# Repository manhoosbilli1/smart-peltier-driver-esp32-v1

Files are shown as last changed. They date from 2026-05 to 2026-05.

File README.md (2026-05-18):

# daanmem_esp32_board_FO2DABBFD842

Smart Peltier driver, ESP32-S3, v1 (v2 in active development)

## At a Glance

- **Status**: Partial / WIP
- **Board size**: 94.01 x 48.1 mm
- **Layers**: 2
- **Components**: 89
- **Key ICs**:
  - U1: AMS1117-3.3
  - U2: LM66200DRLR
  - U3: TPS62932
  - U4: ESP32-S3-WROOM-1-N16R8
  - U6: SM03B-SRSS-TB(LF)(SN)(P)
  - U7,U8: AHT20_C2757850
  - U9: TPS22811LRPWR_C17294173
  - U10: IRS44273LTRPBF

## Schematic

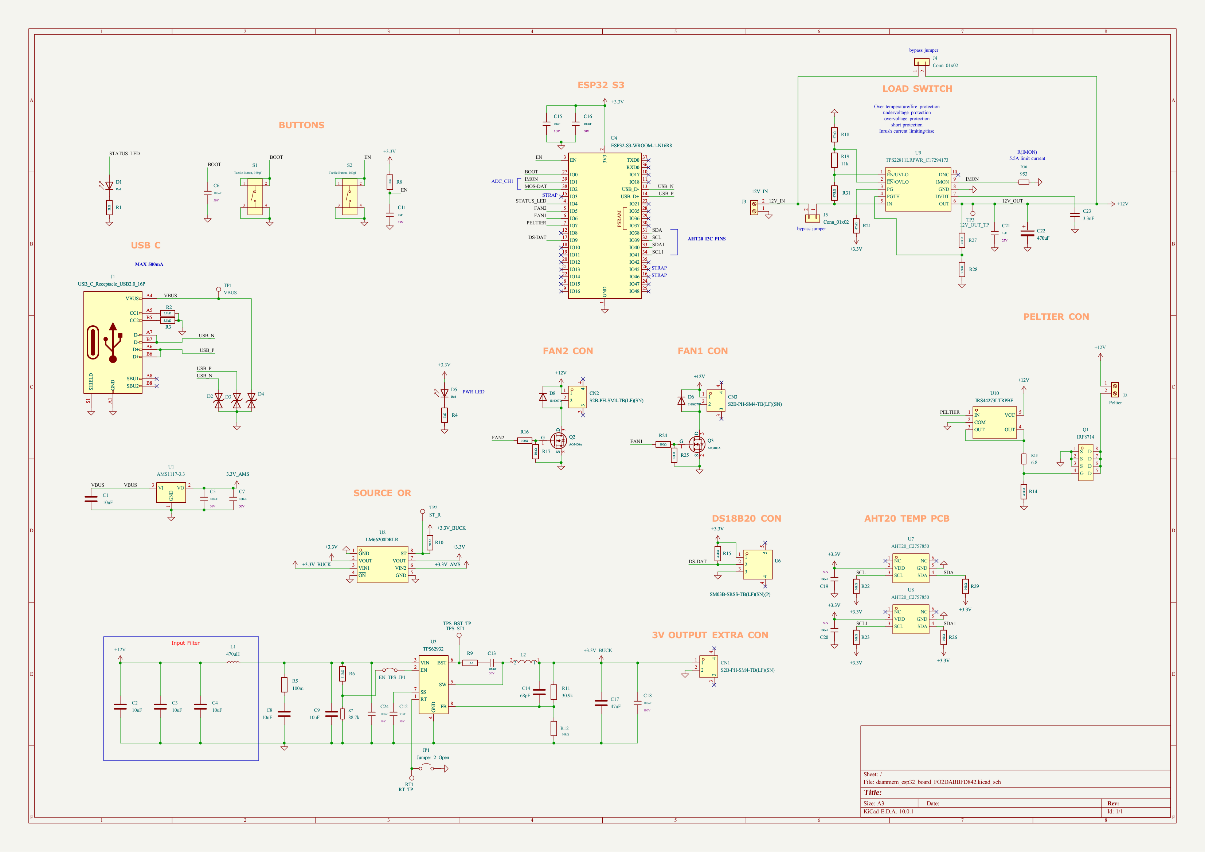
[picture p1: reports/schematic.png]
Schematic


Full PDF: [reports/schematic.pdf](reports/schematic.pdf)

## Component Roles

- **ESP32-S3-WROOM-1** - main MCU; Wi-Fi/BT for remote temperature setpoint + telemetry
- **AMS1117-3.3** - 3.3 V LDO for the MCU core
- **LM66200DRLR** - dual-input ideal-diode / PowerPath controller for clean USB-vs-battery sourcing
- **AO3400A** - 30 V N-channel MOSFETs for switching the Peltier element / fan loads
- **H5VL06B** - small-signal transistors for gate driving / level shifting
- **MCP73831** - single-cell LiPo charger
- **USB-C (16-pin Type-C)** - power + data
- **JST-PH battery connector** (S2B-PH-SM4-TB) for LiPo cell

> v1 reached partial routing (90 footprints placed, 47 tracks, 26 zones). v2 is in active development.

## PCB

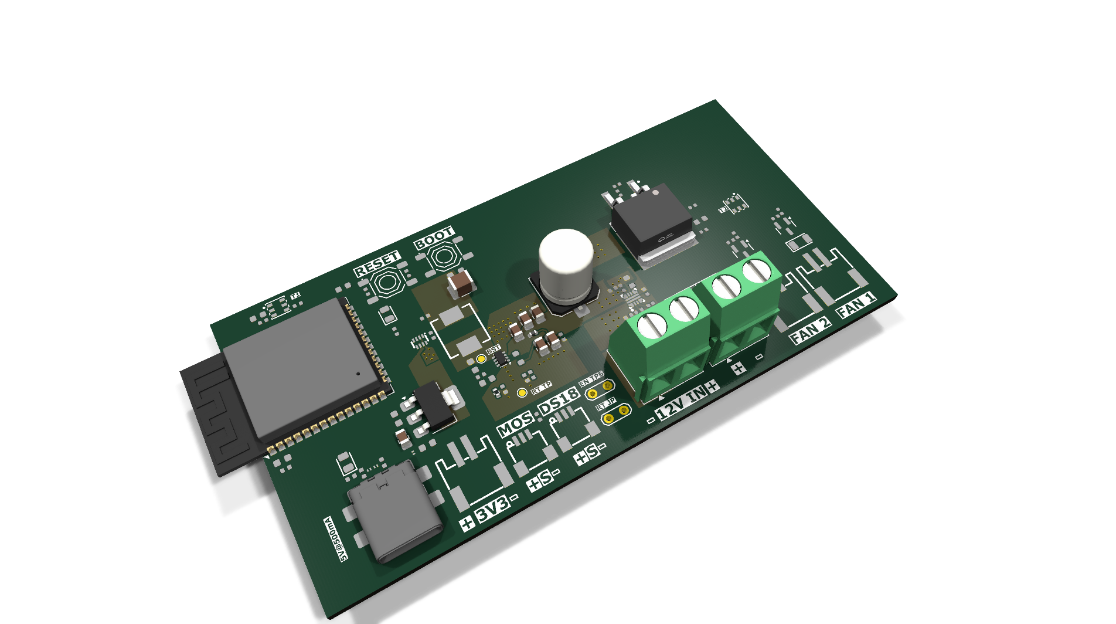
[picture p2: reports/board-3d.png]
3D top


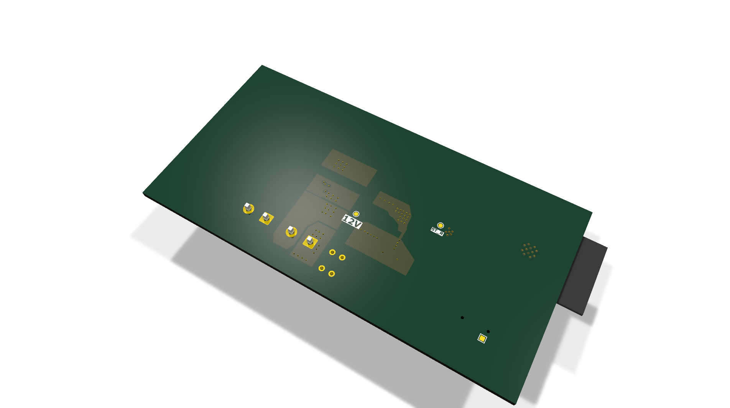
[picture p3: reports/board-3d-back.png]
3D bottom


**Top copper**

PCB top

**Bottom copper**

PCB bottom

## Bill of Materials

| Refs | Value | Footprint | Qty | MPN | LCSC |
|---|---|---|----:|-----|---|
| C1-C4,C8,C9 | 10uF | Capacitor_SMD:C_0805_2012Metric | 6 |  | [C6119887](https://www.lcsc.com/product-detail/_C6119887.html) |
| C5-C7,C13,C16,C19,C20 | 100nF | PCM_JLCPCB:C_0603 | 7 |  | [C14663](https://www.lcsc.com/product-detail/_C14663.html) |
| C11,C21 | 1uF | PCM_JLCPCB:C_0402 | 2 |  | [C52923](https://www.lcsc.com/product-detail/_C52923.html) |
| C12 | 33nF | PCM_JLCPCB:C_0603 | 1 |  | [C21117](https://www.lcsc.com/product-detail/_C21117.html) |
| C14 | 68pF | PCM_JLCPCB:R_0402 | 1 |  | [C76977](https://www.lcsc.com/product-detail/_C76977.html) |
| C15 | 10uF | PCM_JLCPCB:C_0402 | 1 |  | [C15525](https://www.lcsc.com/product-detail/_C15525.html) |
| C17 | 47uF | Capacitor_SMD:C_1210_3225Metric | 1 |  | [C77101](https://www.lcsc.com/product-detail/_C77101.html) |
| C18 | 100nF | PCM_JLCPCB:C_0805 | 1 |  | [C28233](https://www.lcsc.com/product-detail/_C28233.html) |
| C22 | 470uF | Capacitor_SMD:C_Elec_8x10.2 | 1 |  | [C141429](https://www.lcsc.com/product-detail/_C141429.html) |
| C23 | 3.3nF | PCM_JLCPCB:R_0603 | 1 |  | [C77036](https://www.lcsc.com/product-detail/_C77036.html) |
| C24 | 100nF | PCM_JLCPCB:C_0402 | 1 |  | [C1525](https://www.lcsc.com/product-detail/_C1525.html) |
| CN1-CN3 | S2B-PH-SM4-TB(LF)(SN) | :CONN-SMD_P2.00_S2B-PH-SM4-TB-LF-SN | 3 |  |  |
| D1,D5 | Red | PCM_JLCPCB:D_0805 | 2 |  | [C84256](https://www.lcsc.com/product-detail/_C84256.html) |
| D2-D4 | H5VL06B | PCM_JLCPCB:D_DFN0603-2L | 3 |  | [C7420373](https://www.lcsc.com/product-detail/_C7420373.html) |
| D6,D8 | 1N4007W | PCM_JLCPCB:D_SOD-123FL | 2 |  | [C18199088](https://www.lcsc.com/product-detail/_C18199088.html) |
| EN_TPS_JP1 | Jumper_2_Bridged | TestPoint:TestPoint_2Pads_Pitch2.54mm_Drill0.8mm | 1 |  |  |
| J1 | USB_C_Receptacle_USB2.0_16P | Connector_USB:USB_C_Receptacle_GCT_USB4110 | 1 |  |  |
| J2 | Peltier | TerminalBlock_Phoenix:TerminalBlock_Phoenix_MKDS-1,5-2-5.08_1x02_P5.08mm_Horizontal | 1 |  | [C7509570](https://www.lcsc.com/product-detail/_C7509570.html) |
| J3 | 12V_IN | TerminalBlock_Phoenix:TerminalBlock_Phoenix_MKDS-1,5-2-5.08_1x02_P5.08mm_Horizontal | 1 |  | [C7509570](https://www.lcsc.com/product-detail/_C7509570.html) |
| J4,J5 | Conn_01x02 | Connector_JST:JST_XH_B2B-XH-AM_1x02_P2.50mm_Vertical | 2 |  |  |
| JP1 | Jumper_2_Open | TestPoint:TestPoint_2Pads_Pitch2.54mm_Drill0.8mm | 1 |  |  |
| L1 | 470uH | Inductor_SMD:L_0402_1005Metric | 1 |  | [C5788770](https://www.lcsc.com/product-detail/_C5788770.html) |
| L2 | TMPC0624H-6R8MG-D | inductor_6.8u:IND-SMD_L7.0-W6.6 | 1 |  |  |
| Q1 | IRF8714 | :SOIC-8_L4.9-W3.9-P1.27-LS6.0-BL | 1 |  |  |
| Q2,Q3 | AO3400A | PCM_JLCPCB:Q_SOT-23 | 2 |  | [C20917](https://www.lcsc.com/product-detail/_C20917.html) |
| R1 | 2kΩ | PCM_JLCPCB:R_0402 | 1 |  | [C4109](https://www.lcsc.com/product-detail/_C4109.html) |
| R2,R3 | 5.1kΩ | PCM_JLCPCB:R_0402 | 2 |  | [C25905](https://www.lcsc.com/product-detail/_C25905.html) |
| R4 | 1kΩ | PCM_JLCPCB:R_0402 | 1 |  | [C11702](https://www.lcsc.com/product-detail/_C11702.html) |
| R5 | 100m | PCM_JLCPCB:R_0603 | 1 |  | [C713431](https://www.lcsc.com/product-detail/_C713431.html) |
| R6 | 510kΩ | PCM_JLCPCB:R_0402 | 1 |  | [C11616](https://www.lcsc.com/product-detail/_C11616.html) |
| R7 | 88.7k | PCM_JLCPCB:R_0402 | 1 |  | [C477808](https://www.lcsc.com/product-detail/_C477808.html) |
| R8,R12,R17,R22,R23,R25,R26,R29 | 10kΩ | PCM_JLCPCB:R_0402 | 8 |  | [C25744](https://www.lcsc.com/product-detail/_C25744.html) |
| R9 | 0Ω | PCM_JLCPCB:R_0402 | 1 |  | [C17168](https://www.lcsc.com/product-detail/_C17168.html) |
| R10 | 300Ω | PCM_JLCPCB:R_0402 | 1 |  | [C25102](https://www.lcsc.com/product-detail/_C25102.html) |
| R11 | 30.9k | Resistor_SMD:R_0402_1005Metric | 1 |  | [C2085168](https://www.lcsc.com/product-detail/_C2085168.html) |
| R13 | 6.8 | PCM_JLCPCB:R_0402 | 1 |  |  |
| R14,R15 | 4.7kΩ | PCM_JLCPCB:R_0402 | 2 |  | [C25900](https://www.lcsc.com/product-detail/_C25900.html) |
| R16,R24 | 100Ω | PCM_JLCPCB:R_0402 | 2 |  | [C25076](https://www.lcsc.com/product-detail/_C25076.html) |
| R18,R21,R27 | 47kΩ | PCM_JLCPCB:R_0402 | 3 |  | [C25792](https://www.lcsc.com/product-detail/_C25792.html) |
| R19 | 11k | PCM_JLCPCB:R_0402 | 1 |  | [C705643](https://www.lcsc.com/product-detail/_C705643.html) |
| R28 | 5.6kΩ | PCM_JLCPCB:R_0402 | 1 |  | [C25908](https://www.lcsc.com/product-detail/_C25908.html) |
| R30 | 953 | PCM_JLCPCB:R_0402 | 1 |  | [C852958](https://www.lcsc.com/product-detail/_C852958.html) |
| R31 | 470kΩ | PCM_JLCPCB:R_0402 | 1 |  | [C25790](https://www.lcsc.com/product-detail/_C25790.html) |
| RT1 | RT_TP | TestPoint:TestPoint_Pad_D1.0mm | 1 |  |  |
| S1,S2 | Tactile Button, 160gf | PCM_JLCPCB:SW-SMD_4P-L5.1-W5.1-P3.70-LS6.5-TL-2 | 2 |  | [C318884](https://www.lcsc.com/product-detail/_C318884.html) |
| TP1 | VBUS | TestPoint:TestPoint_Pad_1.0x1.0mm | 1 |  |  |
| TP2 | ST_R | TestPoint:TestPoint_Pad_D1.0mm | 1 |  |  |
| TP3 | 12V_OUT_TP | TestPoint:TestPoint_Pad_D1.0mm | 1 |  |  |
| TPS_ST1 | TPS_BST_TP | TestPoint:TestPoint_Pad_D1.0mm | 1 |  |  |
| U1 | AMS1117-3.3 | Package_TO_SOT_SMD:SOT-223-3_TabPin2 | 1 |  | [C6186](https://www.lcsc.com/product-detail/_C6186.html) |
| U2 | LM66200DRLR | LM66200:SOT-583-8_L2.1-W1.2-P0.50-LS1.6-BL | 1 |  |  |
| U3 | TPS62932 | Package_TO_SOT_SMD:SOT-583-8 | 1 |  | [C3032935](https://www.lcsc.com/product-detail/_C3032935.html) |
| U4 | ESP32-S3-WROOM-1-N16R8 | RF_Module:ESP32-S3-WROOM-1 | 1 |  | [C2913202](https://www.lcsc.com/product-detail/_C2913202.html) |
| U6 | SM03B-SRSS-TB(LF)(SN)(P) | :CONN-SMD_SM03B-SRSS-TB-LF-SN-P | 1 |  |  |
| U7,U8 | AHT20_C2757850 | aht20:SENSOR-SMD_L3.0-W3.0-P1.00-BR | 2 |  |  |
| U9 | TPS22811LRPWR_C17294173 | tps22811:VQFN-10_L2.0-W2.0-P0.45-TL | 1 |  |  |
| U10 | IRS44273LTRPBF | :SOT-23-5_L3.0-W1.7-P0.95-LS2.8-BR | 1 |  |  |

_18 of 57 line items don't have an LCSC code in the schematic - search [LCSC](https://www.lcsc.com/) or [JLC parts search](https://jlcsearch.tscircuit.com/) by MPN or footprint when sourcing._

## Files

- `daanmem_esp32_board_FO2DABBFD842.kicad_pro` - KiCad project
- `daanmem_esp32_board_FO2DABBFD842.kicad_sch` - schematic source
- `daanmem_esp32_board_FO2DABBFD842.kicad_pcb` - PCB layout source
- `reports/schematic.pdf` - full schematic (printable)
- `reports/bom.csv` - bill of materials
- `reports/pcb-top.svg`, `reports/pcb-bottom.svg` - copper artwork
- `reports/board-stats.json` - KiCad-generated board statistics

---

_Renders and metadata auto-generated by `Backup-KiCadProject.ps1` using KiCad 10.0._

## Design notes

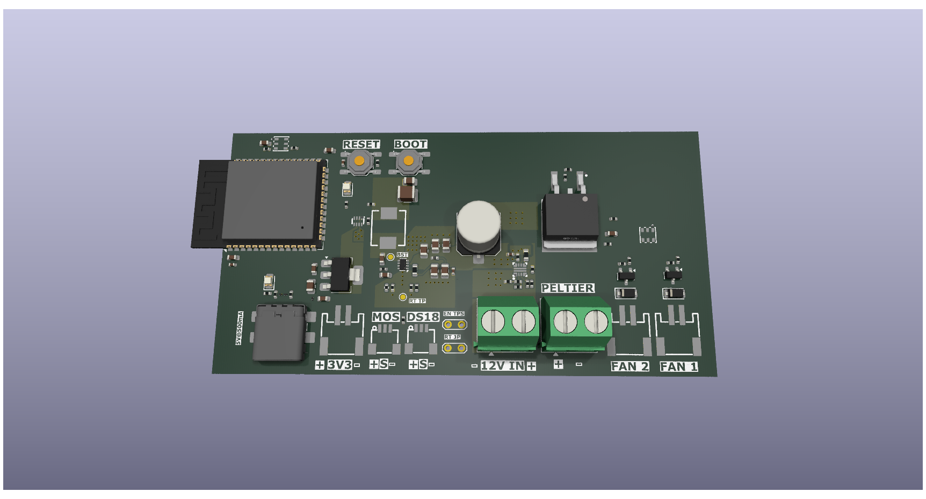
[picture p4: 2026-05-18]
PICTURES/PLACEMENT DRAFT 1.png

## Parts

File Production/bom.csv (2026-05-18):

Designator | Footprint | Quantity | Value | LCSC Part #
C1, C2, C3, C4, C8, C9 | 0805 | 6 | 10uF | C6119887
C11, C21 | C_0402 | 2 | 1uF | C52923
C12 | C_0603 | 1 | 33nF | C21117
C13, C16, C19, C20, C5, C6, C7 | C_0603 | 7 | 100nF | C14663
C14 | R_0402 | 1 | 68pF | C76977
C15 | C_0402 | 1 | 10uF | C15525
C17 | 1210 | 1 | 47uF | C77101
C18 | C_0805 | 1 | 100nF | C28233
C22 | C_Elec_8x10.2 | 1 | 470uF | C141429
C23 | R_0603 | 1 | 3.3nF | C77036
C24 | C_0402 | 1 | 100nF | C1525
CN1, CN2, CN3 | CONN-SMD_P2.00_S2B-PH-SM4-TB-LF-SN | 3 | S2B-PH-SM4-TB(LF)(SN) | C295747
D1, D5 | D_0805 | 2 | Red | C84256
D2, D3, D4 | D_DFN0603-2L | 3 | H5VL06B | C7420373
D6, D8 | D_SOD-123FL | 2 | 1N4007W | C18199088
EN_TPS_JP1 | TestPoint_2Pads_Pitch2.54mm_Drill0.8mm | 1 | Jumper_2_Bridged
J1 | USB_C_Receptacle_GCT_USB4110 | 1 | USB_C_Receptacle_USB2.0_16P
J2 | TerminalBlock_Phoenix_MKDS-1,5-2-5.08_1x02_P5.08mm_Horizontal | 1 | Peltier | C7509570
J3 | TerminalBlock_Phoenix_MKDS-1,5-2-5.08_1x02_P5.08mm_Horizontal | 1 | 12V_IN | C7509570
JP1 | TestPoint_2Pads_Pitch2.54mm_Drill0.8mm | 1 | Jumper_2_Open
L1 | 0402 | 1 | 470uH | C5788770
L2 | IND-SMD_L7.0-W6.6 | 1 | TMPC0624H-6R8MG-D | C357230
Q2, Q3 | Q_SOT-23 | 2 | AO3400A | C20917
Q4 | TO-263-2_L10.0-W9.1-P5.08-LS15.2-TL | 1 | IRF540NSTRLPBF | C23982
R1, R4 | R_0402 | 2 | 2kΩ | C4109
R10 | R_0402 | 1 | 300Ω | C25102
R11 | 0402 | 1 | 30.9k | C2085168
R12, R17, R22, R23, R25, R26, R29, R8 | R_0402 | 8 | 10kΩ | C25744
R13, R16, R24 | R_0402 | 3 | 100Ω | C25076
R14 | R_0402 | 1 | 100kΩ | C25741
R15 | R_0402 | 1 | 4.7kΩ | C25900
R18, R20, R21, R27 | R_0402 | 4 | 47kΩ | C25792
R19 | R_0402 | 1 | 11k | C705643
R2, R3 | R_0402 | 2 | 5.1kΩ | C25905
R28 | R_0402 | 1 | 5.6kΩ | C25908
R30 | R_0402 | 1 | 953 | C852958
R5 | R_0603 | 1 | 100m | C713431
R6 | R_0402 | 1 | 510kΩ | C11616
R7 | R_0402 | 1 | 88.7k | C477808
R9 | R_0402 | 1 | 0Ω | C17168
RT1 | TestPoint_Pad_D1.0mm | 1 | RT_TP
S1, S2 | SW-SMD_4P-L5.1-W5.1-P3.70-LS6.5-TL-2 | 2 | Tactile Button, 160gf | C318884
TP1 | TestPoint_Pad_1.0x1.0mm | 1 | VBUS
TP2 | TestPoint_Pad_D1.0mm | 1 | ST_R
TP3 | TestPoint_Pad_D1.0mm | 1 | 12V_OUT_TP
TPS_ST1 | TestPoint_Pad_D1.0mm | 1 | TPS_BST_TP
U1 | SOT-223-3_TabPin2 | 1 | AMS1117-3.3 | C6186
U2 | SOT-583-8_L2.1-W1.2-P0.50-LS1.6-BL | 1 | LM66200DRLR | C3235556
U3 | SOT-583-8 | 1 | TPS62932 | C3032935
U4 | ESP32-S3-WROOM-1 | 1 | ESP32-S3-WROOM-1-N16R8 | C2913202
U5, U6 | CONN-SMD_SM03B-SRSS-TB-LF-SN-P | 2 | SM03B-SRSS-TB(LF)(SN)(P) | C160403
U7, U8 | SENSOR-SMD_L3.0-W3.0-P1.00-BR | 2 | AHT20_C2757850 | C2757850
U9 | VQFN-10_L2.0-W2.0-P0.45-TL | 1 | TPS22811LRPWR_C17294173 | C17294173

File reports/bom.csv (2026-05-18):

Refs | Value | Footprint | Qty | Description | Mfr | MPN | LCSC
C1-C4,C8,C9 | 10uF | Capacitor_SMD:C_0805_2012Metric | 6 | 10uF ±10% 25V Ceramic Capacitor X5R 0805 |  |  | C6119887
C5-C7,C13,C16,C19,C20 | 100nF | PCM_JLCPCB:C_0603 | 7 | 50V 100nF X7R ±10% 0603 Multilayer Ceramic Capacitors MLCC - SMD/SMT ROHS | YAGEO |  | C14663
C11,C21 | 1uF | PCM_JLCPCB:C_0402 | 2 | 25V 1uF X5R ±10% 0402 Multilayer Ceramic Capacitors MLCC - SMD/SMT ROHS | Samsung Electro-Mechanics |  | C52923
C12 | 33nF | PCM_JLCPCB:C_0603 | 1 | 50V 33nF X7R ±10% 0603 Multilayer Ceramic Capacitors MLCC - SMD/SMT ROHS | Samsung Electro-Mechanics |  | C21117
C14 | 68pF | PCM_JLCPCB:R_0402 | 1 | 68pF ±5% 50V Ceramic Capacitor C0G 0402 |  |  | C76977
C15 | 10uF | PCM_JLCPCB:C_0402 | 1 | 6.3V 10uF X5R ±20% 0402 Multilayer Ceramic Capacitors MLCC - SMD/SMT ROHS | Samsung Electro-Mechanics |  | C15525
C17 | 47uF | Capacitor_SMD:C_1210_3225Metric | 1 | 47uF ±10% 16V Ceramic Capacitor X5R 1210 |  |  | C77101
C18 | 100nF | PCM_JLCPCB:C_0805 | 1 | 100V 100nF X7R ±10% 0805 Multilayer Ceramic Capacitors MLCC - SMD/SMT ROHS | Samsung Electro-Mechanics |  | C28233
C22 | 470uF | Capacitor_SMD:C_Elec_8x10.2 | 1 | Polarized capacitor |  |  | C141429
C23 | 3.3nF | PCM_JLCPCB:R_0603 | 1 | Unpolarized capacitor, small symbol |  |  | C77036
C24 | 100nF | PCM_JLCPCB:C_0402 | 1 | 16V 100nF X7R ±10% 0402 Multilayer Ceramic Capacitors MLCC - SMD/SMT ROHS | Samsung Electro-Mechanics |  | C1525
CN1-CN3 | S2B-PH-SM4-TB(LF)(SN) | :CONN-SMD_P2.00_S2B-PH-SM4-TB-LF-SN | 3
D1,D5 | Red | PCM_JLCPCB:D_0805 | 2 | 25mA Colorless transparent lens 67mcd~195mcd -30°C~+85°C 615nm~630nm Individual diode Red 130° 65mW 1.6V~2.6V 0805 LED Indication - Discrete ROHS | Foshan NationStar Optoelectronics |  | C84256
D2-D4 | H5VL06B | PCM_JLCPCB:D_DFN0603-2L | 3 | 8A 10V 80W 5.6V Bidirectional 5V DFN0603-2L ESD and Surge Protection (TVS/ESD) ROHS | hongjiacheng |  | C7420373
D6,D8 | 1N4007W | PCM_JLCPCB:D_SOD-123FL | 2 | Independent Type 1A 1kV 1V@1.0A SOD-123FL Diodes - General Purpose ROHS | hongjiacheng |  | C18199088
EN_TPS_JP1 | Jumper_2_Bridged | TestPoint:TestPoint_2Pads_Pitch2.54mm_Drill0.8mm | 1 | Jumper, 2-pole, closed/bridged
J1 | USB_C_Receptacle_USB2.0_16P | Connector_USB:USB_C_Receptacle_GCT_USB4110 | 1 | USB 2.0-only 16P Type-C Receptacle connector
J2 | Peltier | TerminalBlock_Phoenix:TerminalBlock_Phoenix_MKDS-1,5-2-5.08_1x02_P5.08mm_Horizontal | 1 | Generic screw terminal, single row, 01x02, script generated (kicad-library-utils/schlib/autogen/connector/) |  |  | C7509570
J3 | 12V_IN | TerminalBlock_Phoenix:TerminalBlock_Phoenix_MKDS-1,5-2-5.08_1x02_P5.08mm_Horizontal | 1 | Generic screw terminal, single row, 01x02, script generated (kicad-library-utils/schlib/autogen/connector/) |  |  | C7509570
J4,J5 | Conn_01x02 | Connector_JST:JST_XH_B2B-XH-AM_1x02_P2.50mm_Vertical | 2 | Generic connector, single row, 01x02, script generated (kicad-library-utils/schlib/autogen/connector/)
JP1 | Jumper_2_Open | TestPoint:TestPoint_2Pads_Pitch2.54mm_Drill0.8mm | 1 | Jumper, 2-pole, open
L1 | 470uH | Inductor_SMD:L_0402_1005Metric | 1 | 1.2A 140mΩ 1.2A ±20% 470nH Multilayer inductor 0402 Fixed Inductors RoHS |  |  | C5788770
L2 | TMPC0624H-6R8MG-D | inductor_6.8u:IND-SMD_L7.0-W6.6 | 1
Q1 | IRF8714 | :SOIC-8_L4.9-W3.9-P1.27-LS6.0-BL | 1
Q2,Q3 | AO3400A | PCM_JLCPCB:Q_SOT-23 | 2 | 30V 5.7A 26.5mΩ@10V,5.7A 1.4W 1.5V@250uA 1 N-Channel SOT-23-3L MOSFETs ROHS | Alpha & Omega Semicon |  | C20917
R1 | 2kΩ | PCM_JLCPCB:R_0402 | 1 | 62.5mW Thick Film Resistors 50V ±100ppm/°C ±1% 2kΩ 0402 Chip Resistor - Surface Mount ROHS | UNI-ROYAL(Uniroyal Elec) |  | C4109
R2,R3 | 5.1kΩ | PCM_JLCPCB:R_0402 | 2 | 62.5mW Thick Film Resistors 50V ±100ppm/°C ±1% 5.1kΩ 0402 Chip Resistor - Surface Mount ROHS | UNI-ROYAL(Uniroyal Elec) |  | C25905
R4 | 1kΩ | PCM_JLCPCB:R_0402 | 1 | 62.5mW Thick Film Resistors 50V ±100ppm/°C ±1% 1kΩ 0402 Chip Resistor - Surface Mount ROHS | UNI-ROYAL(Uniroyal Elec) |  | C11702
R5 | 100m | PCM_JLCPCB:R_0603 | 1 | 0ppm/℃~+300ppm/℃ 100mW 100mΩ Current Sense Resistor SMD ±1% 0603 Current Sense Resistors / Shunt Resistors ROHS |  |  | C713431
R6 | 510kΩ | PCM_JLCPCB:R_0402 | 1 | 62.5mW Thick Film Resistors 50V ±100ppm/°C ±1% 510kΩ 0402 Chip Resistor - Surface Mount ROHS | UNI-ROYAL(Uniroyal Elec) |  | C11616
R7 | 88.7k | PCM_JLCPCB:R_0402 | 1 | Resistor, small symbol |  |  | C477808
R8,R12,R17,R22,R23,R25,R26,R29 | 10kΩ | PCM_JLCPCB:R_0402 | 8 | 62.5mW Thick Film Resistors 50V ±100ppm/°C ±1% 10kΩ 0402 Chip Resistor - Surface Mount ROHS | UNI-ROYAL(Uniroyal Elec) |  | C25744
R9 | 0Ω | PCM_JLCPCB:R_0402 | 1 | 62.5mW Thick Film Resistors 50V ±800ppm/°C ±1% 0Ω 0402 Chip Resistor - Surface Mount ROHS | UNI-ROYAL(Uniroyal Elec) |  | C17168
R10 | 300Ω | PCM_JLCPCB:R_0402 | 1 | 62.5mW Thick Film Resistors 50V ±100ppm/°C ±1% 300Ω 0402 Chip Resistor - Surface Mount ROHS | UNI-ROYAL(Uniroyal Elec) |  | C25102
R11 | 30.9k | Resistor_SMD:R_0402_1005Metric | 1 | 30.9kΩ 62.5mW 50V Thick Film Resistor ±1% ±100ppm/℃ 0402 Chip Resistor - Surface Mount RoHS |  |  | C2085168
R13 | 6.8 | PCM_JLCPCB:R_0402 | 1 | Resistor, small symbol
R14,R15 | 4.7kΩ | PCM_JLCPCB:R_0402 | 2 | 62.5mW Thick Film Resistors 50V ±100ppm/°C ±1% 4.7kΩ 0402 Chip Resistor - Surface Mount ROHS | UNI-ROYAL(Uniroyal Elec) |  | C25900
R16,R24 | 100Ω | PCM_JLCPCB:R_0402 | 2 | 62.5mW Thick Film Resistors 50V ±1% ±200ppm/°C 100Ω 0402 Chip Resistor - Surface Mount ROHS | UNI-ROYAL(Uniroyal Elec) |  | C25076
R18,R21,R27 | 47kΩ | PCM_JLCPCB:R_0402 | 3 | 62.5mW Thick Film Resistors 50V ±100ppm/°C ±1% 47kΩ 0402 Chip Resistor - Surface Mount ROHS | UNI-ROYAL(Uniroyal Elec) |  | C25792
R19 | 11k | PCM_JLCPCB:R_0402 | 1 | Resistor |  |  | C705643
R28 | 5.6kΩ | PCM_JLCPCB:R_0402 | 1 | 62.5mW Thick Film Resistors 50V ±100ppm/°C ±1% 5.6kΩ 0402 Chip Resistor - Surface Mount ROHS | UNI-ROYAL(Uniroyal Elec) |  | C25908
R30 | 953 | PCM_JLCPCB:R_0402 | 1 | Resistor, small symbol |  |  | C852958
R31 | 470kΩ | PCM_JLCPCB:R_0402 | 1 | 62.5mW Thick Film Resistors 50V ±100ppm/°C ±1% 470kΩ 0402 Chip Resistor - Surface Mount ROHS | UNI-ROYAL(Uniroyal Elec) |  | C25790
RT1 | RT_TP | TestPoint:TestPoint_Pad_D1.0mm | 1 | test point
S1,S2 | Tactile Button, 160gf | PCM_JLCPCB:SW-SMD_4P-L5.1-W5.1-P3.70-LS6.5-TL-2 | 2 | None Without 50mA 5.1mm 100000 Times 160gf 12V 5.1mm 1.5mm Round Button Standing paste SPST SMD Tactile Switches ROHS | XKB Connectivity |  | C318884
TP1 | VBUS | TestPoint:TestPoint_Pad_1.0x1.0mm | 1 | test point
TP2 | ST_R | TestPoint:TestPoint_Pad_D1.0mm | 1 | test point
TP3 | 12V_OUT_TP | TestPoint:TestPoint_Pad_D1.0mm | 1 | test point
TPS_ST1 | TPS_BST_TP | TestPoint:TestPoint_Pad_D1.0mm | 1 | test point
U1 | AMS1117-3.3 | Package_TO_SOT_SMD:SOT-223-3_TabPin2 | 1 | 1A Low Dropout regulator, positive, 3.3V fixed output, SOT-223 |  |  | C6186
U2 | LM66200DRLR | LM66200:SOT-583-8_L2.1-W1.2-P0.50-LS1.6-BL | 1
U3 | TPS62932 | Package_TO_SOT_SMD:SOT-583-8 | 1 | 3.8-30V, 2A Synchronous Buck Converters with pulse frequency modulation (PFM), SOT583-8 |  |  | C3032935
U4 | ESP32-S3-WROOM-1-N16R8 | RF_Module:ESP32-S3-WROOM-1 | 1 | RF Module, ESP32-S3 SoC, Wi-Fi 802.11b/g/n, Bluetooth, BLE, 32-bit, 3.3V, onboard antenna, SMD |  |  | C2913202
U6 | SM03B-SRSS-TB(LF)(SN)(P) | :CONN-SMD_SM03B-SRSS-TB-LF-SN-P | 1
U7,U8 | AHT20_C2757850 | aht20:SENSOR-SMD_L3.0-W3.0-P1.00-BR | 2
U9 | TPS22811LRPWR_C17294173 | tps22811:VQFN-10_L2.0-W2.0-P0.45-TL | 1
U10 | IRS44273LTRPBF | :SOT-23-5_L3.0-W1.7-P0.95-LS2.8-BR | 1

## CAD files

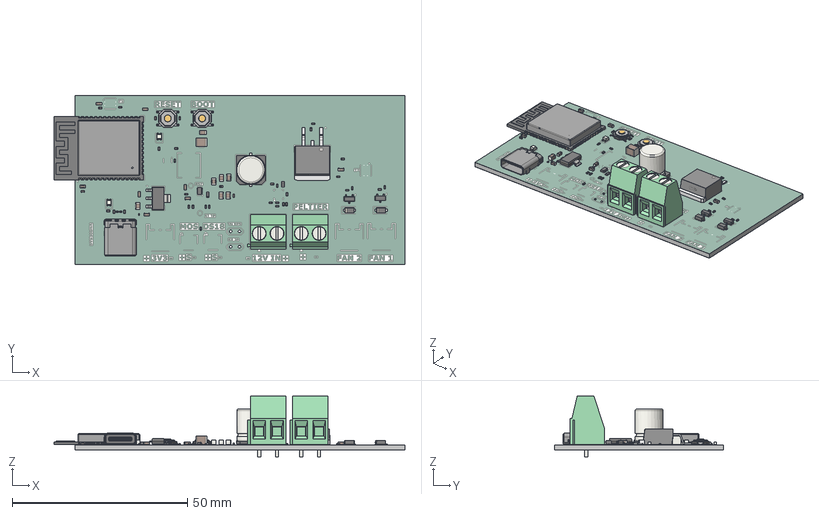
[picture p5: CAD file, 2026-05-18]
daanmem_esp32_board_FO2DABBFD842.step
100.0 x 48.1 x 17.3 mm
R_0402 x 29
C_0603 x 8
C_0805_2012Metric x 6
DFN0603-2_L0.6-W0.3-P0.40-RD x 3
TO-263-2_L10.2-W8.7-H4.5_LS15.2-P2.54
D_SOD-123FL x 2
C_0402 x 4
C_Elec_8x10.2
D_0805 x 2
SOT-583-8
USB_C_Receptacle_Amphenol_12401610E4-2A
R_0603 x 2
C_0805
Q_SOT-23 x 2
R_0402_1005Metric
TerminalBlock_Phoenix_MKDS-1,5-2-5.08_1x02_P5.08mm_Horizontal x 2
SW-SMD_4P-L5.1-W5.1-P3.70-LS6.5-TL-2 x 2
C_1210_3225Metric
L_0402_1005Metric
ESP32-S3-WROOM-1
SOT-223
daanmem_esp32_board_FO2DABBFD842_silkscreen x 2
daanmem_esp32_board_FO2DABBFD842_soldermask x 2
daanmem_esp32_board_FO2DABBFD842_PCB

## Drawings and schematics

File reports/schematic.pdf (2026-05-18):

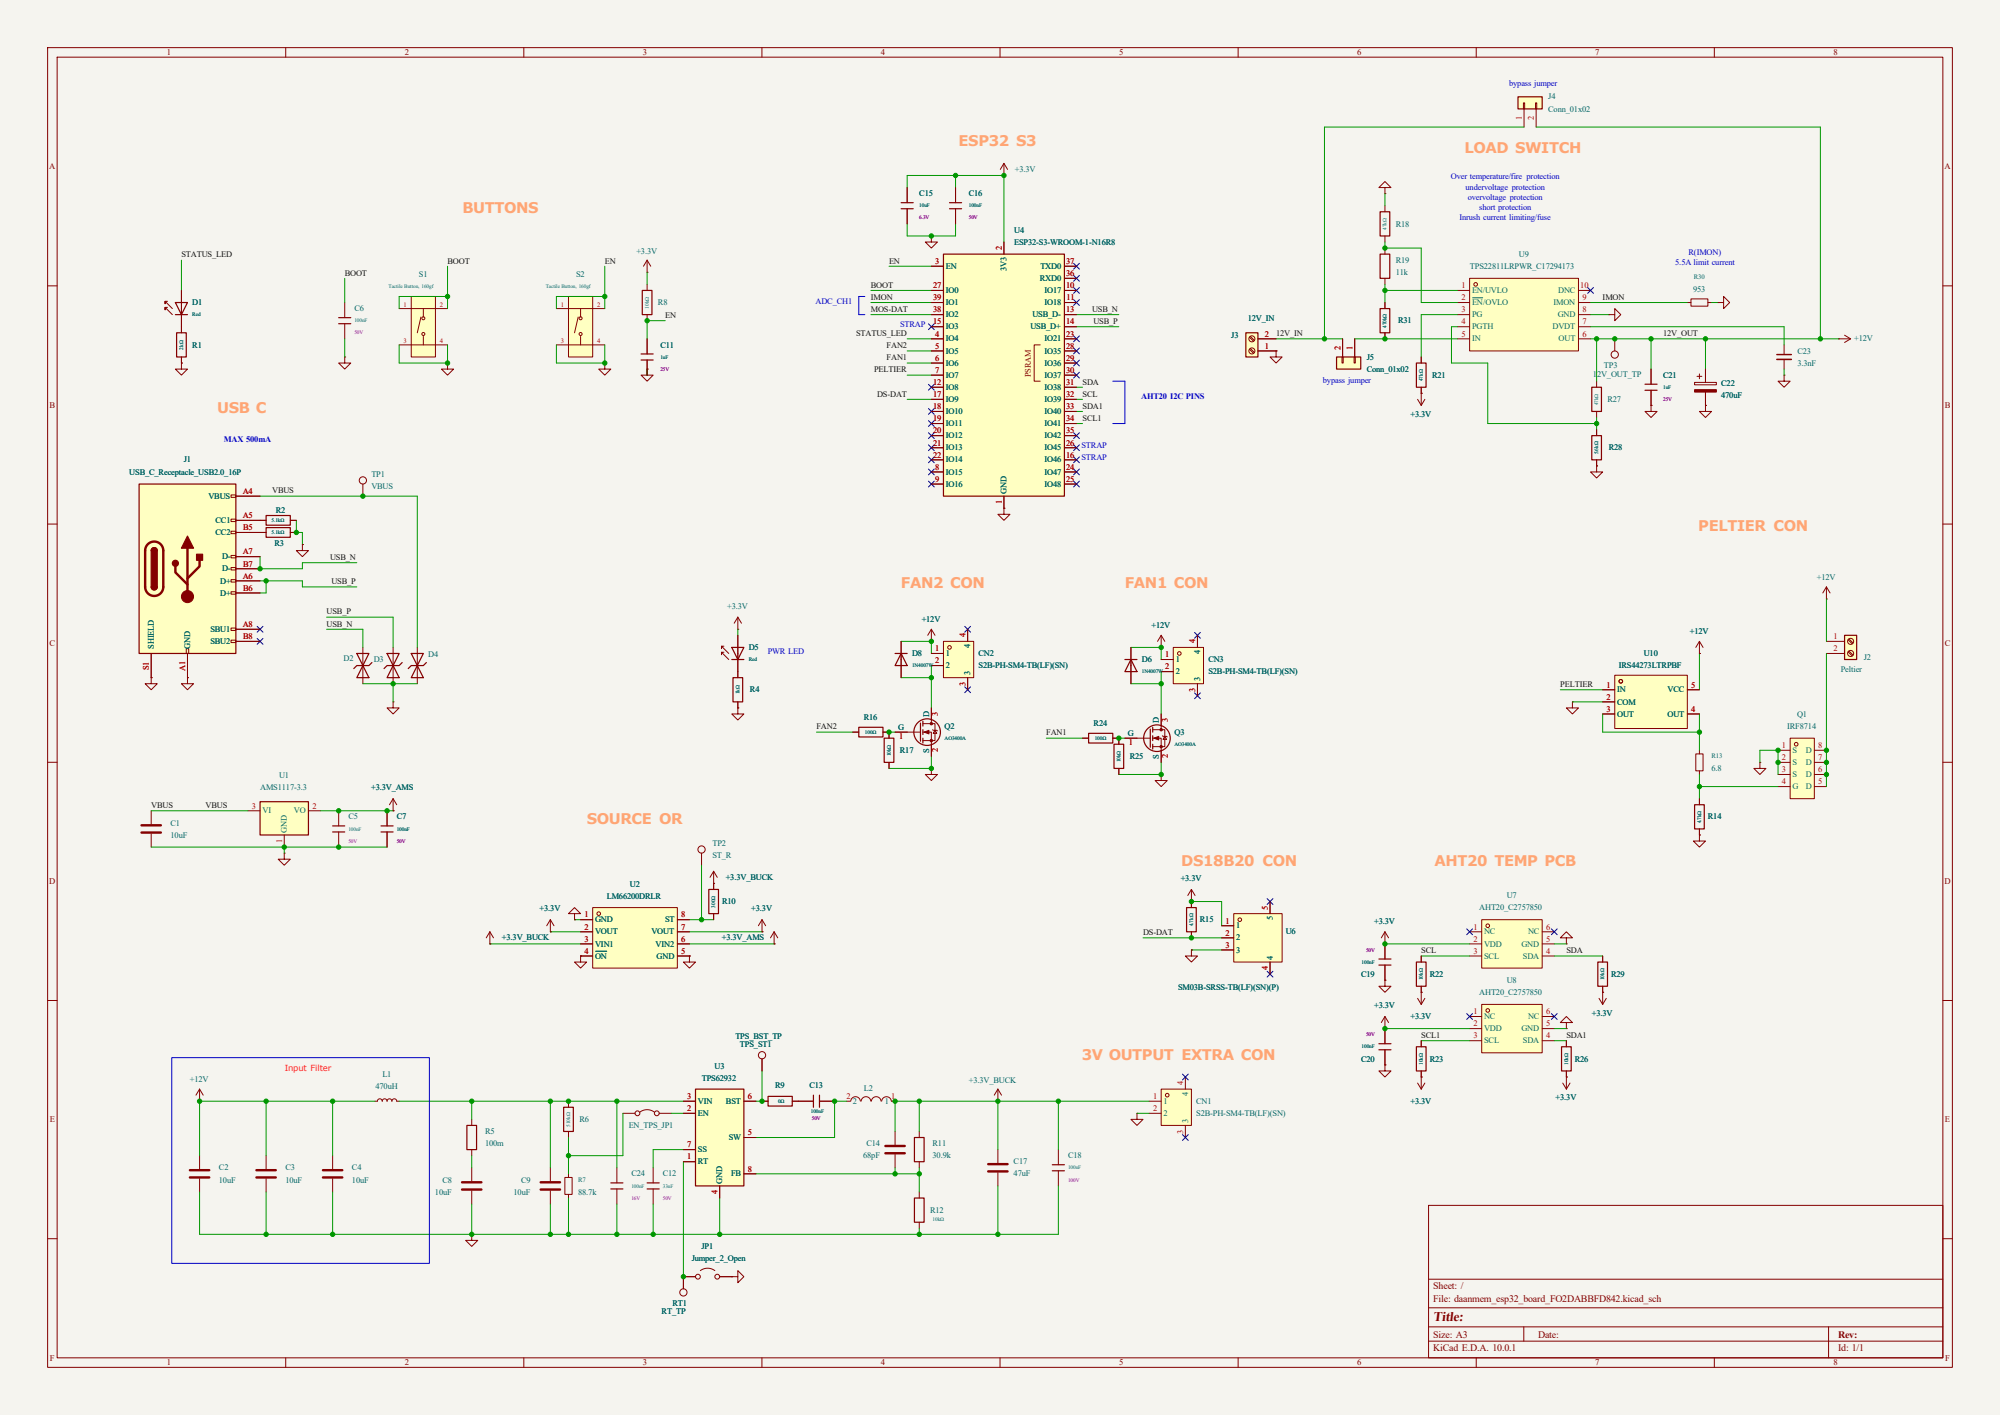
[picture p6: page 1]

bypass jumper Over temperature/fire protection

Inrush current limiting/fuse MAX 500mA

R(IMON) 5.5A limit current 3V OUTPUT EXTRA CON

EN/UVLO 1 EN/OVLO 2 PG 3 PGTH 4

4 SW 5 BST 6 SS 7 FB 8 U3 TPS62932 +3.3V_BUCK +3.3V

4 SW 5 BST 6 SS 7 FB 8 +3.3V_BUCK

5 U6 SM03B-SRSS-TB(LF)(SN)(P)

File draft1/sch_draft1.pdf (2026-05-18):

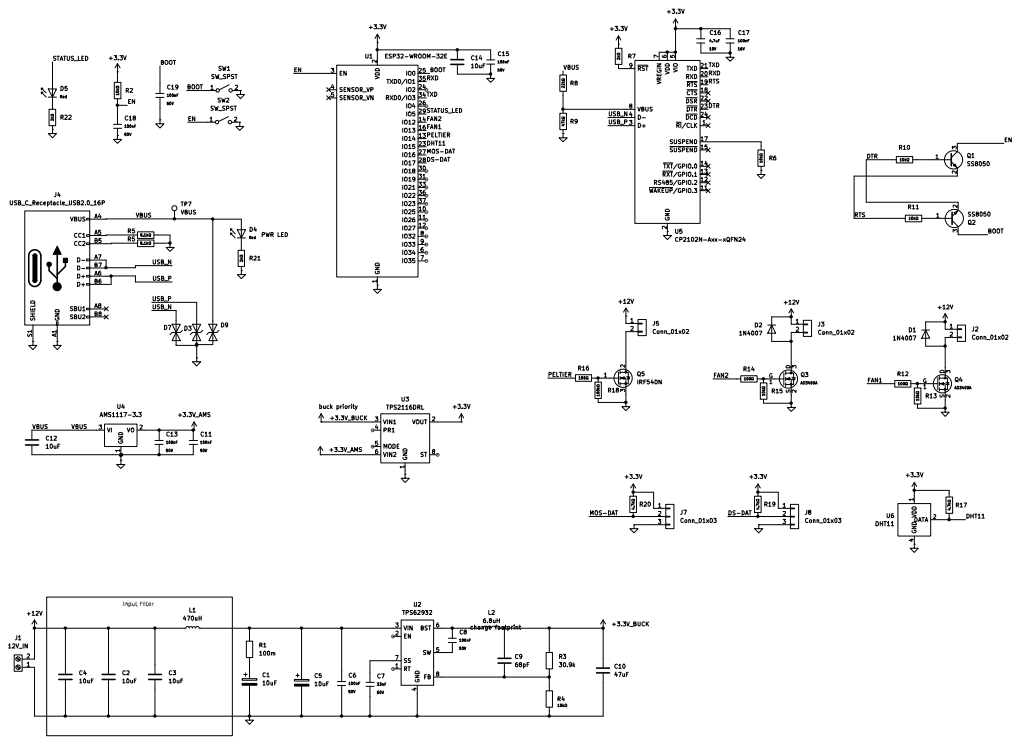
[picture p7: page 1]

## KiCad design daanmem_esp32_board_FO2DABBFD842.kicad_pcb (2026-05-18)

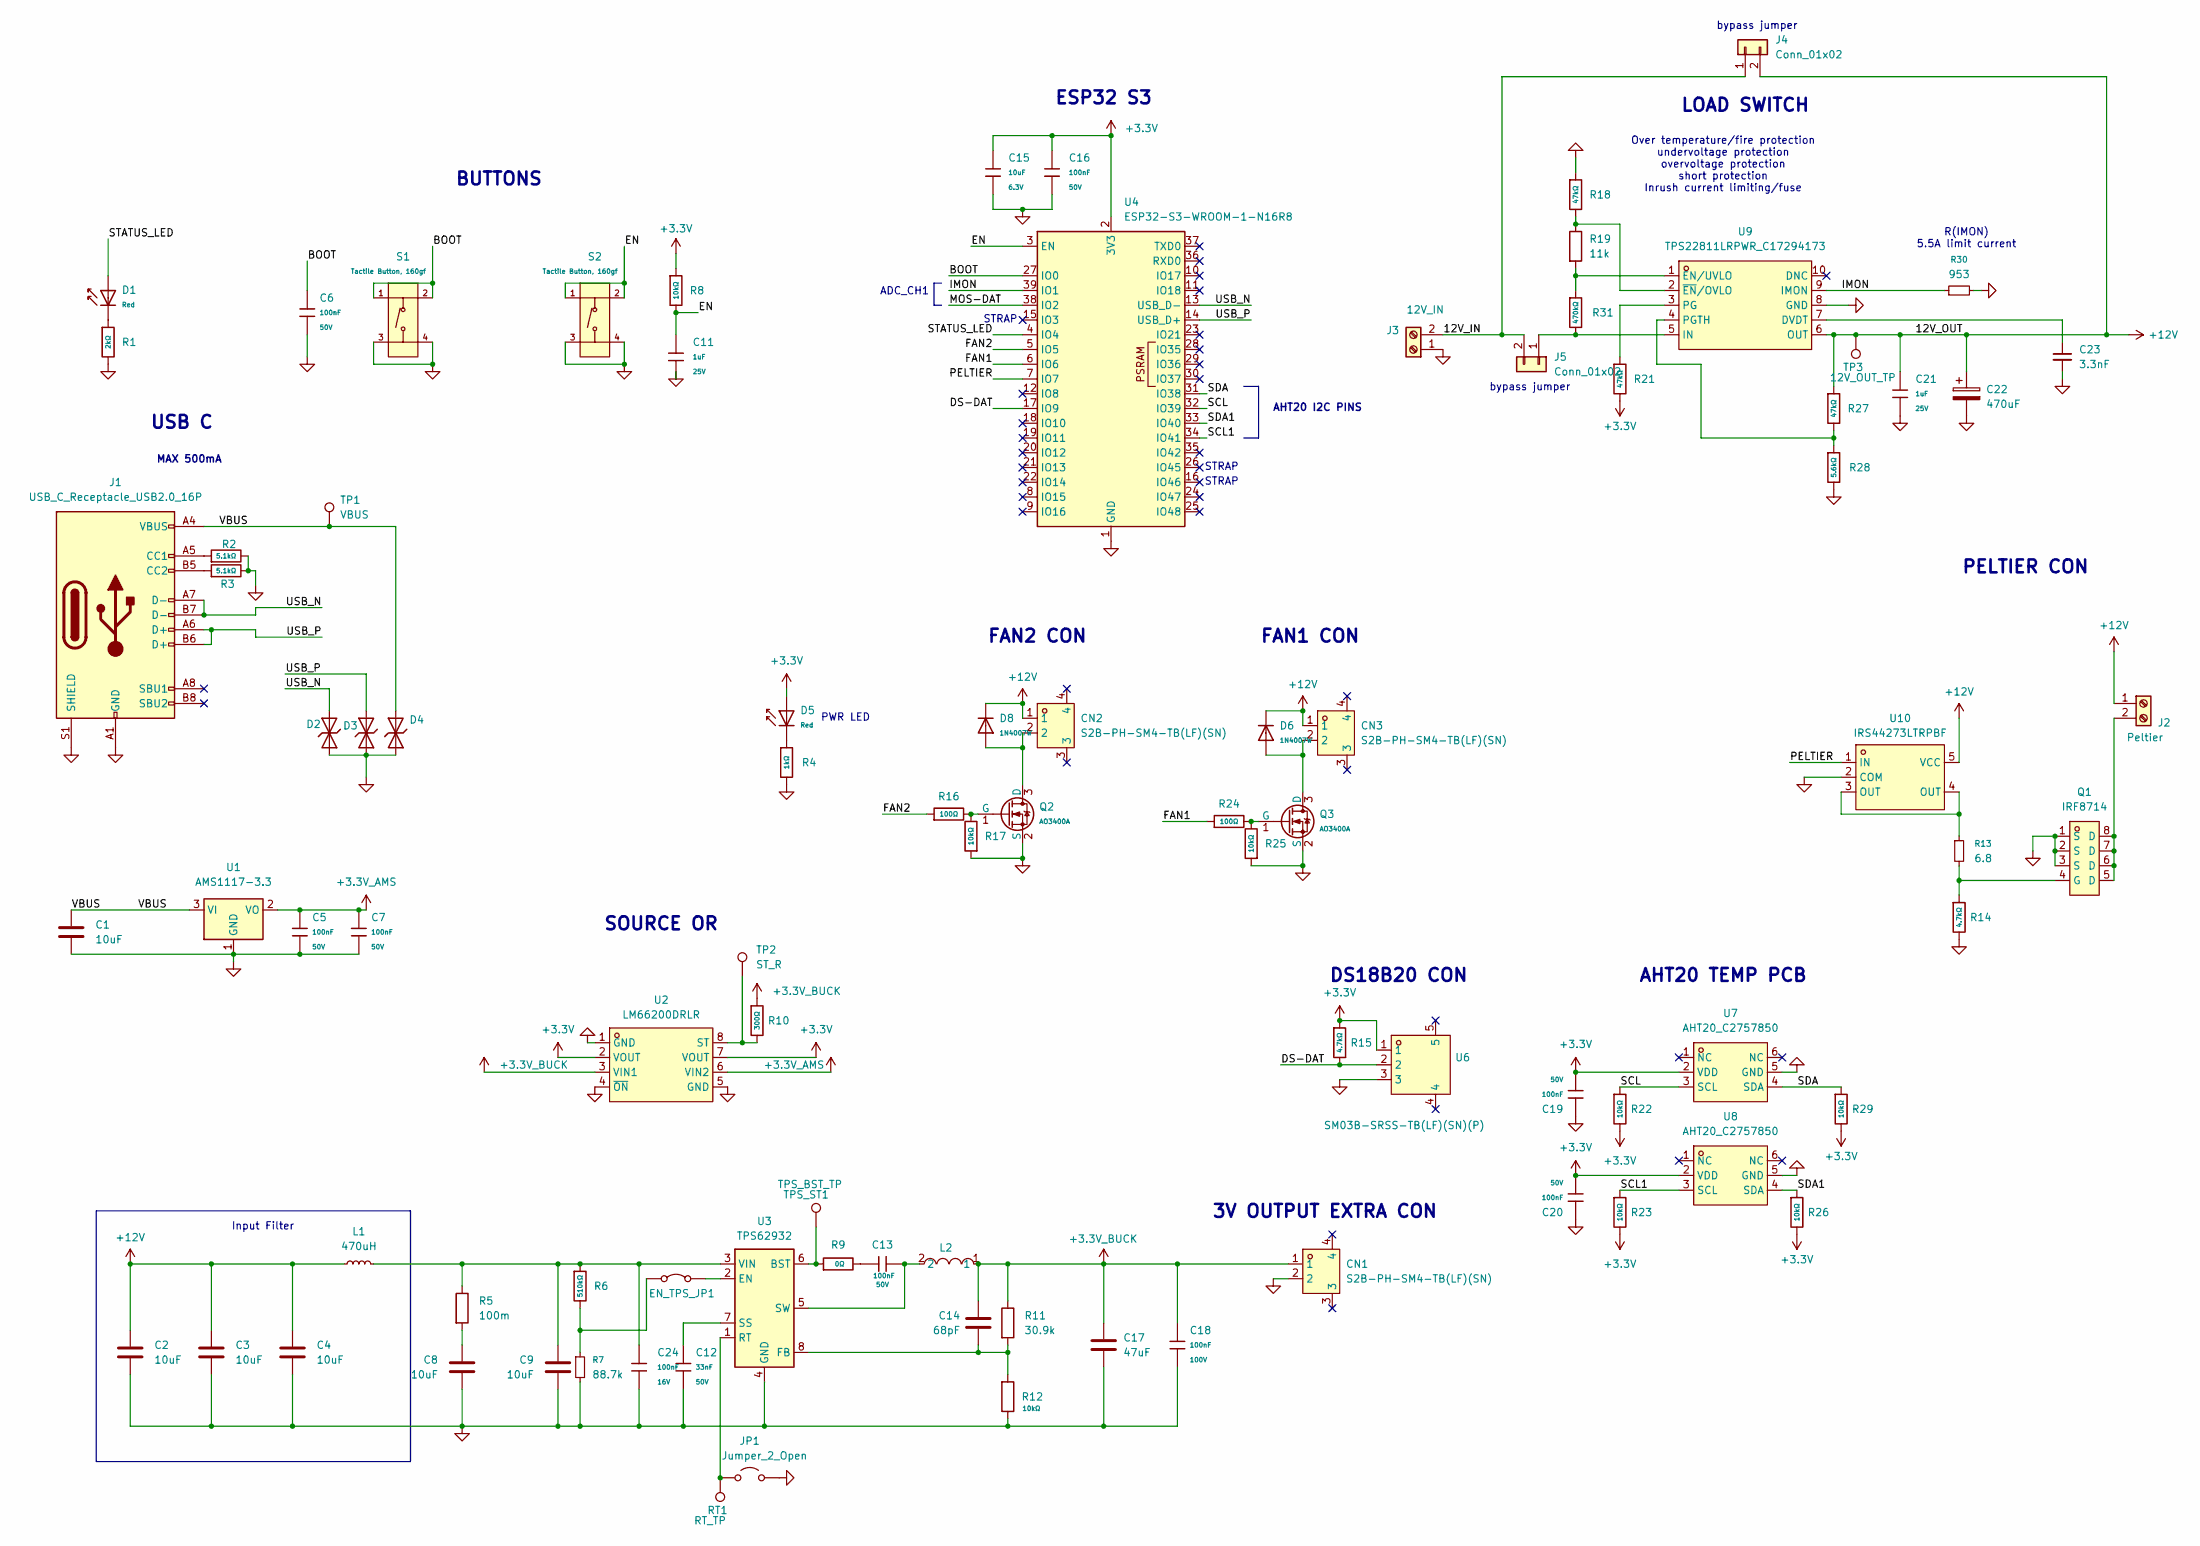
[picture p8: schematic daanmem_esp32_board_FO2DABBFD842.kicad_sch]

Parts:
C1, C2, C3, C4, C8, C9: 10uF; C_0805_2012Metric; LCSC C6119887
C5, C6, C7, C13, C16, C19, C20: 100nF; C_0603; Voltage Rated 50V; Tolerance ±10%; Part CC0603KRX7R9BB104; LCSC C14663
C11, C21: 1uF; C_0402; Voltage Rated 25V; Tolerance ±10%; Part CL05A105KA5NQNC; LCSC C52923
C12: 33nF; C_0603; Voltage Rated 50V; Tolerance ±10%; Part CL10B333KB8NNNC; LCSC C21117
C14: 68pF; R_0402; LCSC C76977
C15: 10uF; C_0402; Voltage Rated 6.3V; Tolerance ±20%; Part CL05A106MQ5NUNC; LCSC C15525
C17: 47uF; C_1210_3225Metric; LCSC C77101
C18: 100nF; C_0805; Voltage Rated 100V; Tolerance ±10%; Part CL21B104KCFNNNE; LCSC C28233
C22: 470uF; C_Elec_8x10.2; LCSC C141429
C23: 3.3nF; R_0603; LCSC C77036
C24: 100nF; C_0402; Voltage Rated 16V; Tolerance ±10%; Part CL05B104KO5NNNC; LCSC C1525
CN1, CN2, CN3: S2B-PH-SM4-TB(LF)(SN); CONN-SMD_P2.00_S2B-PH-SM4-TB-LF-SN; LCSC Part C295747
D1, D5: Red; D_0805; Forward Voltage (VF) 1.6V~2.6V; Part NCD0805R1; LCSC C84256
D2, D3, D4: H5VL06B; D_DFN0603-2L; Clamping Voltage@Ipp 10V; Breakdown Voltage (VBR) 5.6V; Part H5VL06B; LCSC C7420373
D6, D8: 1N4007W; D_SOD-123FL; Part 1N4007W; LCSC C18199088
EN_TPS_JP1: Jumper_2_Bridged; TestPoint_2Pads_Pitch2.54mm_Drill0.8mm
J1: USB_C_Receptacle_USB2.0_16P; USB_C_Receptacle_GCT_USB4110
J2: Peltier; TerminalBlock_Phoenix_MKDS-1,5-2-5.08_1x02_P5.08mm_Horizont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; LCSC C7509570
J3: 12V_IN; TerminalBlock_Phoenix_MKDS-1,5-2-5.08_1x02_P5.08mm_Horizont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; LCSC C7509570
J4, J5: Conn_01x02; JST_XH_B2B-XH-AM_1x02_P2.50mm_Vertical
JP1: Jumper_2_Open; TestPoint_2Pads_Pitch2.54mm_Drill0.8mm
L1: 470uH; L_0402_1005Metric; LCSC C5788770
L2: TMPC0624H-6R8MG-D; IND-SMD_L7.0-W6.6; LCSC Part C357230
Q1: IRF8714; SOIC-8_L4.9-W3.9-P1.27-LS6.0-BL; LCSC Part C5350863
Q2, Q3: AO3400A; Q_SOT-23; Part AO3400A; LCSC C20917
R1: 2kΩ; R_0402; Overload Voltage (Max) 50V; Tolerance ±1%; Part 0402WGF2001TCE; LCSC C4109
R2, R3: 5.1kΩ; R_0402; Overload Voltage (Max) 50V; Tolerance ±1%; Part 0402WGF5101TCE; LCSC C25905
R4: 1kΩ; R_0402; Overload Voltage (Max) 50V; Tolerance ±1%; Part 0402WGF1001TCE; LCSC C11702
R5: 100m; R_0603; LCSC C713431
R6: 510kΩ; R_0402; Overload Voltage (Max) 50V; Tolerance ±1%; Part 0402WGF5103TCE; LCSC C11616
R7: 88.7k; R_0402; LCSC C477808
R8, R12, R17, R22, R23, R25, R26, R29: 10kΩ; R_0402; Overload Voltage (Max) 50V; Tolerance ±1%; Part 0402WGF1002TCE; LCSC C25744
R9: 0Ω; R_0402; Overload Voltage (Max) 50V; Tolerance ±1%; Part 0402WGF0000TCE; LCSC C17168
R10: 300Ω; R_0402; Overload Voltage (Max) 50V; Tolerance ±1%; Part 0402WGF3000TCE; LCSC C25102
R11: 30.9k; R_0402_1005Metric; LCSC C2085168
R13: 6.8; R_0402
R14, R15: 4.7kΩ; R_0402; Overload Voltage (Max) 50V; Tolerance ±1%; Part 0402WGF4701TCE; LCSC C25900
R16, R24: 100Ω; R_0402; Overload Voltage (Max) 50V; Tolerance ±1%; Part 0402WGF1000TCE; LCSC C25076
R18, R21, R27: 47kΩ; R_0402; Overload Voltage (Max) 50V; Tolerance ±1%; Part 0402WGF4702TCE; LCSC C25792
R19: 11k; R_0402; LCSC C705643
R28: 5.6kΩ; R_0402; Overload Voltage (Max) 50V; Tolerance ±1%; Part 0402WGF5601TCE; LCSC C25908
R30: 953; R_0402; LCSC C852958
R31: 470kΩ; R_0402; Overload Voltage (Max) 50V; Tolerance ±1%; Part 0402WGF4703TCE; LCSC C25790
RT1: RT_TP; TestPoint_Pad_D1.0mm
S1, S2: Tactile Button, 160gf; SW-SMD_4P-L5.1-W5.1-P3.70-LS6.5-TL-2; Voltage Rating (Dc) 12V; Part TS-1187A-B-A-B; LCSC C318884
TP1: VBUS; TestPoint_Pad_1.0x1.0mm
TP2: ST_R; TestPoint_Pad_D1.0mm
TP3: 12V_OUT_TP; TestPoint_Pad_D1.0mm
TPS_ST1: TPS_BST_TP; TestPoint_Pad_D1.0mm
U1: AMS1117-3.3; SOT-223-3_TabPin2; LCSC C6186
U2: LM66200DRLR; SOT-583-8_L2.1-W1.2-P0.50-LS1.6-BL; LCSC Part C3235556
U3: TPS62932; SOT-583-8; LCSC C3032935
U4: ESP32-S3-WROOM-1-N16R8; ESP32-S3-WROOM-1; LCSC C2913202
U6: SM03B-SRSS-TB(LF)(SN)(P); CONN-SMD_SM03B-SRSS-TB-LF-SN-P; LCSC Part C160403
U7, U8: AHT20_C2757850; SENSOR-SMD_L3.0-W3.0-P1.00-BR; LCSC Part C2757850
U9: TPS22811LRPWR_C17294173; VQFN-10_L2.0-W2.0-P0.45-TL; LCSC Part C17294173
U10: IRS44273LTRPBF; SOT-23-5_L3.0-W1.7-P0.95-LS2.8-BR; LCSC Part C126909

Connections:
+3.3V_AMS: C5.1, C7.1, U1.2 (VO), U2.6 (VIN2)
+3.3V_BUCK: C14.1, C17.1, C18.1, CN1.1, L2.1, R10.1, R11.1, U2.3 (VIN1)
+12V: C2.1, C3.1, C4.1, C21.1, C22.1, CN2.1, CN3.1, D6.1, D8.1, J2.1, J4.2, L1.1, R27.1, TP3.1, U9.6 (OUT), U10.5 (VCC)
/12V_IN: J3.2, J4.1, J5.1, J5.2, R31.2, U9.5 (IN); also elsewhere on the board
/BOOT: C6.1, S1.1 (A), S1.2 (B), U4.27 (IO0)
/DS-DAT: R15.2, U4.17 (IO9), U6.2
/EN: C11.1, R8.2, S2.1 (A), S2.2 (B), U4.3 (EN)
/FAN1: R24.1, U4.6 (IO6)
/FAN2: R16.1, U4.5 (IO5)
/IMON: R30.1, U4.39 (IO1), U9.9 (IMON)
/MOS-DAT: U4.38 (IO2); also elsewhere on the board
/PELTIER: R13.1, U4.7 (IO7), U10.1 (IN), U10.3 (OUT), U10.4 (OUT)
/SCL: R22.1, U4.32 (IO39), U7.3 (SCL)
/SCL1: R23.1, U4.34 (IO41), U8.3 (SCL)
/SDA: R29.1, U4.31 (IO38), U7.4 (SDA)
/SDA1: R26.1, U4.33 (IO40), U8.4 (SDA)
/STATUS_LED: D1.2, U4.4 (IO4)
/USB_N: D2.2, J1.A7 (D-), J1.B7 (D-), U4.13 (USB_D-)
/USB_P: D3.2, J1.A6 (D+), J1.B6 (D+), U4.14 (USB_D+)
GND: C1.2, C2.2, C3.2, C4.2, C5.2, C6.2, C7.2, C8.2, C9.2, C11.2, C12.2, C15.2, C16.2, C17.2, C18.2, C19.1, C20.1, C21.2, C22.2, C23.2, C24.2, CN1.2, D2.1, D3.1, D4.1, J1.A1 (GND), J1.A12 (GND), J1.B1 (GND), J1.B12 (GND), J1.S1 (SHIELD), J3.1, JP1.2 (B), Q1.1 (S), Q1.2 (S), Q1.3 (S), Q2.2 (S), Q3.2 (S), R1.2, R2.2, R3.2, R4.2, R7.2, R12.2, R14.2, R17.1, R18.1, R25.1, R28.2, R30.2, S1.3 (C), S1.4 (D), S2.3 (C), S2.4 (D), U1.1 (GND), U2.1 (GND), U2.4 (~ON), U2.5 (GND), U3.4 (GND), U4.1 (GND), U4.40 (GND), U4.41 (GND), U6.3, U7.5 (GND), U8.5 (GND), U9.8 (GND), U10.2 (COM); also elsewhere on the board
unnamed: C8.1, R5.2
unnamed: C13.1, R9.2
unnamed: D1.1, R1.1
unnamed: D5.1, R4.1
unnamed: EN_TPS_JP1.1 (A), R6.2, R7.1
unnamed: EN_TPS_JP1.2 (B), U3.2 (EN)
unnamed: J1.A5 (CC1), R2.1
unnamed: J1.B5 (CC2), R3.1
unnamed 28: J2.2, Q1.5 (D), Q1.6 (D), Q1.7 (D), Q1.8 (D); also elsewhere on the board
unnamed: JP1.1 (A), RT1.1, U3.1 (RT)
unnamed: CN2.2, D8.2, Q2.3 (D)
unnamed: Q2.1 (G), R16.2, R17.2
unnamed: CN3.2, D6.2, Q3.3 (D)
unnamed: Q3.1 (G), R24.2, R25.2
unnamed 34: Q1.4 (G), R13.2, R14.1; also elsewhere on the board
unnamed: R10.2, TP2.1, U2.8 (ST)
unnamed: R9.1, TPS_ST1.1, U3.6 (BST)
unnamed: C14.2, R11.2, R12.1, U3.8 (FB)
unnamed: C12.1, U3.7 (SS)
unnamed: C13.2, L2.2, U3.5 (SW)
unnamed: C9.1, C24.1, L1.2, R5.1, R6.1, U3.3 (VIN)
unnamed: C23.1, U9.7 (DVDT)
unnamed 42: R19.2, R31.1, U9.1 (EN/UVLO); also elsewhere on the board
unnamed: R21.1, U9.3 (PG)
unnamed: R27.2, R28.1, U9.4 (PGTH)
unnamed: R18.2, R19.1, U9.2 (~EN/OVLO)

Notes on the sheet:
STRAP
LOAD SWITCH
Over temperature/fire protection undervoltage protection overvoltage protection short protection Inrush current limiting/fuse
MAX 500mA
ESP32 S3
bypass jumper
BUTTONS
ADC_CH1
Input Filter
SOURCE OR
FAN2 CON
FAN1 CON
3V OUTPUT EXTRA CON
R(IMON) 5.5A limit current
PELTIER CON
AHT20 I2C PINS
USB C
PWR LED
DS18B20 CON
AHT20 TEMP PCB

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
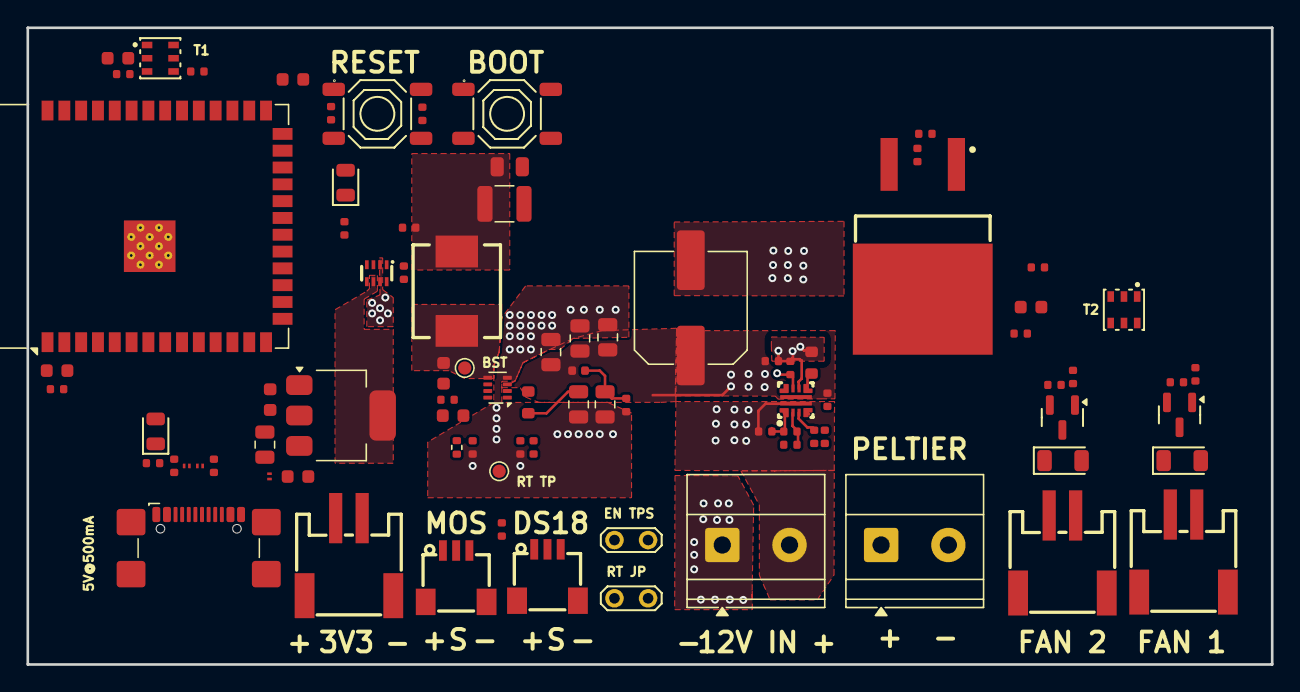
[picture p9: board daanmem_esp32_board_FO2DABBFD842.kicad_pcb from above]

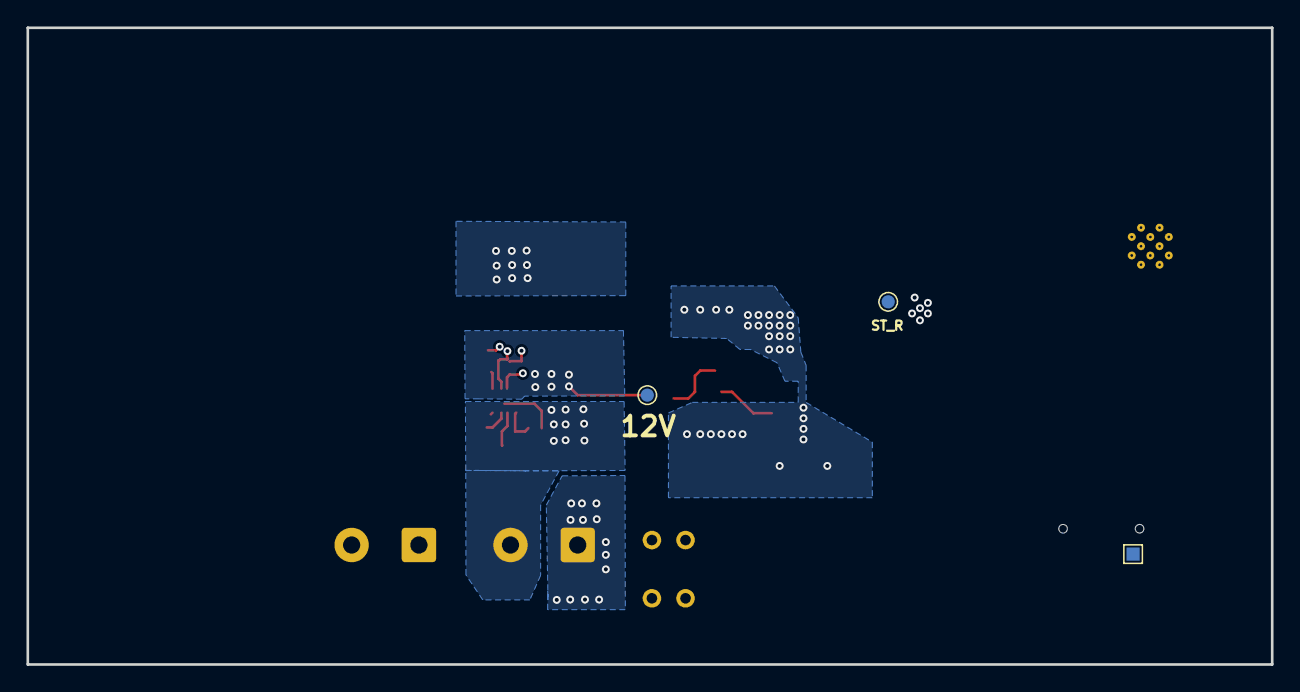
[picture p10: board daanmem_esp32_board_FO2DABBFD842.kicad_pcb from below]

Board: 2 copper layers, 94.0 x 48.1 mm, 89 parts (3 on the bottom side), 48 nets.

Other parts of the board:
Q4: IRF540NSTRLPBF; TO-263-2_L10.0-W9.1-P5.08-LS15.2-TL
R20: 47kΩ; R_0402
U5: SM03B-SRSS-TB(LF)(SN)(P); CONN-SMD_SM03B-SRSS-TB-LF-SN-P

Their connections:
/12V_IN: R20.2; also elsewhere on the board
/MOS-DAT: U5.2; also elsewhere on the board
GND: Q4.3 (S), U5.3; also elsewhere on the board
unnamed 28: Q4.4 (D); also elsewhere on the board
unnamed 34: Q4.1 (G); also elsewhere on the board
unnamed 42: R20.1; also elsewhere on the board

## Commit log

2026-05-18 Initial backup: schematic, PCB, renders, BOM
    [bom.csv, daanmem_esp32_board_FO2DABBFD842.kicad_pcb, daanmem_esp32_board_FO2DABBFD842.kicad_sch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]
2026-05-18 Enrich README: schematic PNG, component roles, BOM table
